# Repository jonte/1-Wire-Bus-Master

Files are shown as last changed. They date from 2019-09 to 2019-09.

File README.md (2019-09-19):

1-Wire Bus Master
=================

These are KiCad schematics and project files for a 1-Wire Bus Master module,
capable of mastering 8 1-Wire busses.

This module is meant to be connected to, and driven by, a host uC, such as a Raspberry Pi or an Arduino. The host uC must be capable of I2C communication.

The module is powered by the Maxim DS2482 1-Wire bus master chip.

Features
--------

- Break-out of 8 1-Wire busses from the DS2482
- Screw terminal connectors for host and all 8 busses
- 4.5cm x 4cm footprint
- 4 x 3.4mm mounting holes (M3 clearance hole size)
- Optional pull-up resistors for SDA and SCL (toggled via jumpers)

Notes for Raspberry Pi
----------------------

The Raspberry Pi has internal pull-ups for I2C, so the J1 and J2 jumpers should not be populated when using a Raspberry Pi.

The I2C bus must be enabled to communicate with the board, this can be done using `raspi-config`, in the `Interfacing Options -> I2C` menu.

The ds2482 kernel module, included in the mainline kernels, is compatible with this board and can be used as follows:

    modprobe ds2482
    echo ds2482 0x18 > /sys/bus/i2c/devices/i2c-1/new_device

A systemd service file for Raspberry Pi is available in `systemd/ds2482.service`.

In the above example, `0x18` is the board's I2C address. This will remain valid as long as the `AD0-2` pins are connected to ground. If you change this, you will also have to change the board I2C address.

The bus master devices, and any connected 1-Wire devices will appear under `/sys/bus/w1/devices/`.

3D Rendering
------------

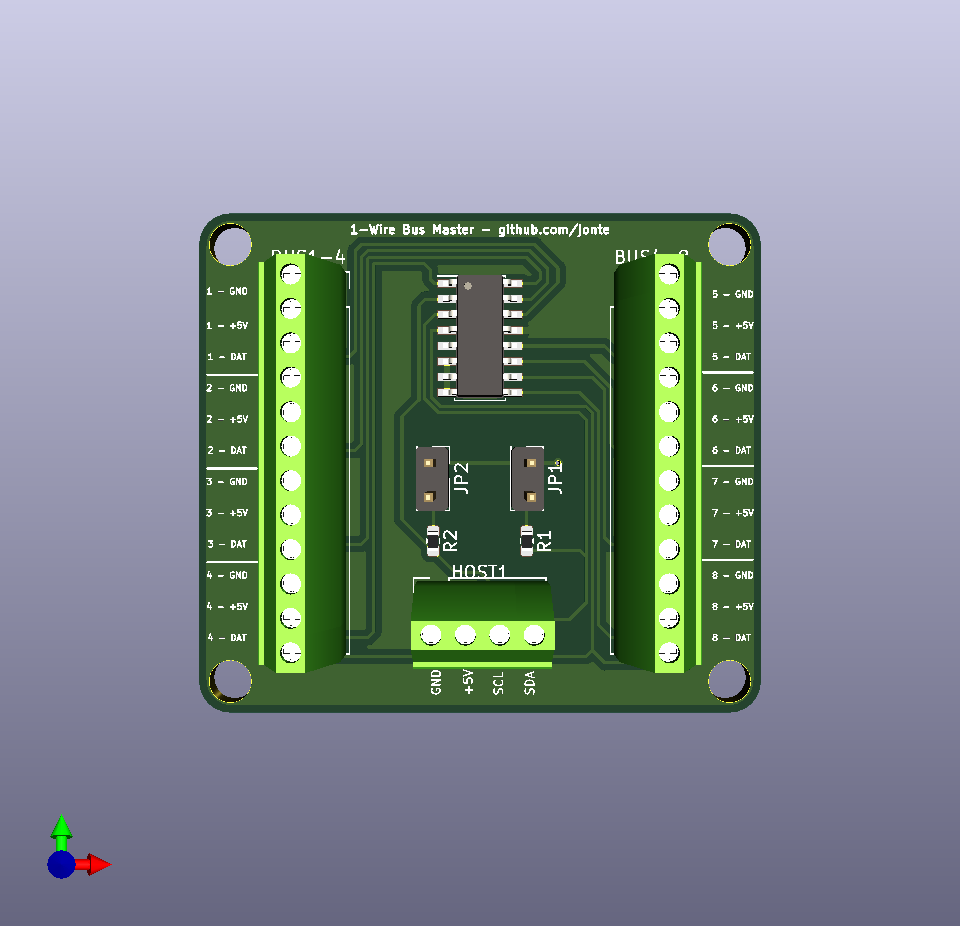
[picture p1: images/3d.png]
3D Rendering 3D rendering, using Phoenix MPT screw terminal blocks


License
-------

This project is licensed under the CERN Open Hardware Licence v1.2.

See LICENSE.txt

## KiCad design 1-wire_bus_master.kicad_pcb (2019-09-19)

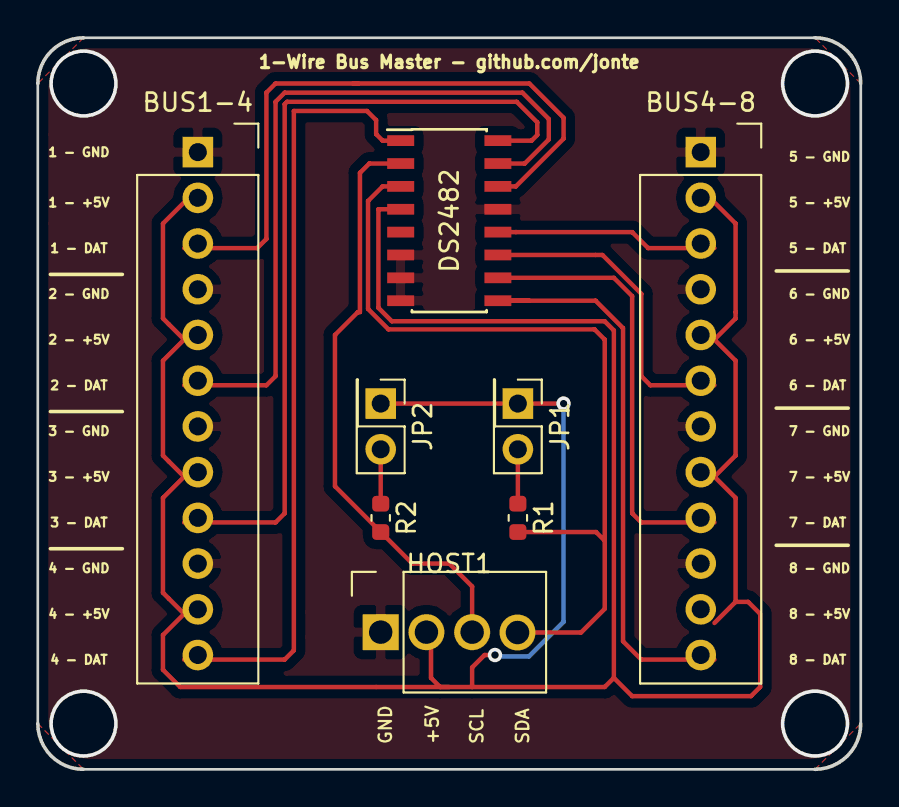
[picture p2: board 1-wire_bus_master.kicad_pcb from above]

Board: 2 copper layers, 45.7 x 40.6 mm, 8 parts (0 on the bottom side), 14 nets.

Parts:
BUS1-4, BUS4-8: Conn_01x12; OSTVN12A150
DS2482: DS2482-800; SOIC-16_3.9x9.9mm_P1.27mm
HOST1: Conn_01x04; OSTVN04A150
JP1: JMP_PU_SDA; PinHeader_2x01_P2.54mm_Vertical
JP2: JMP_PU_SCL; PinHeader_2x01_P2.54mm_Vertical
R1, R2: 1k7; R_0603_1608Metric

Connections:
+5V: BUS1-4.2, BUS1-4.5, BUS1-4.8, BUS1-4.11, BUS4-8.2, BUS4-8.5, BUS4-8.8, BUS4-8.11, DS2482.4, HOST1.2, JP1.1, JP2.1
/BUS1: BUS1-4.3, DS2482.14
/BUS2: BUS1-4.6, DS2482.15
/BUS3: BUS1-4.9, DS2482.16
/BUS4: BUS1-4.12, DS2482.1
/BUS5: BUS4-8.3, DS2482.12
/BUS6: BUS4-8.6, DS2482.11
/BUS7: BUS4-8.9, DS2482.10
/BUS8: BUS4-8.12, DS2482.9
GND: BUS1-4.1, BUS1-4.4, BUS1-4.7, BUS1-4.10, BUS4-8.1, BUS4-8.4, BUS4-8.7, BUS4-8.10, DS2482.6, DS2482.7, DS2482.8, DS2482.13, HOST1.1
unnamed: DS2482.2, HOST1.3, R2.2
unnamed: DS2482.3, HOST1.4, R1.2
unnamed: JP1.2, R1.1
unnamed: JP2.2, R2.1

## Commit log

2019-09-07 Initial commit
    This adds the first revision of the board, as it looks when sent to the
    first round of manufacturing.
    [1-wire_bus_master.kicad_pcb, 1-wire_bus_master.sch]
2019-09-19 Make SDA & SCL pull-ups optional, document Pi usage
    [1-wire_bus_master.kicad_pcb, 1-wire_bus_master.sch]
